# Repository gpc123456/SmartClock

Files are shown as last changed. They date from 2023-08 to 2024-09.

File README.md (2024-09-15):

# SmartClock: A simple but powerful desktop gadget

## Features
- 2.9 "ink screen, excellent viewing Angle and very low power consumption, and can be displayed all the time. 
- Automatic network time synchronization ensures that the time is always accurate. 
- Supports monitoring of environmental information, including temperature, humidity, and air pressure. 
- Switch to Pomodoro Timer at any time to make work and study more efficient. 
- Get weather conditions through the network, showing tomorrow's weather and precipitation probability
- Can be powered by a built-in battery for 7 days, using the universal USB-C charging port 
- Compact and portable, you can take it anywhere. 

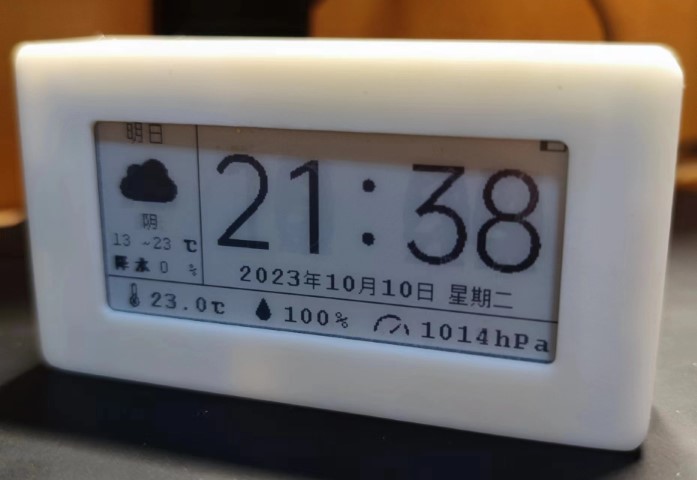
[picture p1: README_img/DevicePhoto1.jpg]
DevicePhoto1


## Version 2.0 Updates:
- Upgrade the device enclosure by no longer using clips but instead using screws to secure the lid and the PCB, making assembly and disassembly easier. 
- Modified the battery level measurement circuit to reduce power consumption during battery level measurements. 
- The PCB uses a four-layer board design for better electrical performance. Additionally, the placement of the temperature and humidity sensor has been optimized to minimize the impact of heat generated during charging on the sensor. 
- Adding a timezone setting feature. 
- The built-in ArduinoJson library simplifies the environmental configuration steps.

## Making Guidelines 
There are the following folders in this project: 
- Hardware
- Model
- bin
- GUI_Picture
- src 

The following will show you how to make a SmartClock by explaining what the files in these folders do.

### Hardware 
In the Hardware folder, you can see the following two types of files: 
- **Compressed package ending with PCB:** These are the production files of the circuit board. You need to provide these two files to the corresponding circuit board manufacturer to make the circuit board used in this project. 
- **PDF file ending with Schematic:** This is the schematic diagram of the circuit board to help you understand the composition of the circuit. 

**Please note**: 
When you complete the circuit board, you also need to weld the corresponding components according to the schematic diagram before it can work normally. The following are some key device selection references: 
- MCU: ESP-12F (ESP8266) 
- E-Paper: E029A01
- Battery: 1000-2000 mAH (Size: [L:52mm, W:34mm, H:<10mm])

### Model
This is the 3D design file of the SmartClock shell, if you need a shell for it, please use a 3D printer to print two files, they are the main body shell and the upper cover. 

**Please note**: 
To secure the top cover, you need to insert knurled nuts into the screw holes on the main body. The size of the knurled nuts and the corresponding parameters of the screws are as follows: 
- knurled nuts: M2*3.5(Outside diameter)*3(Height)
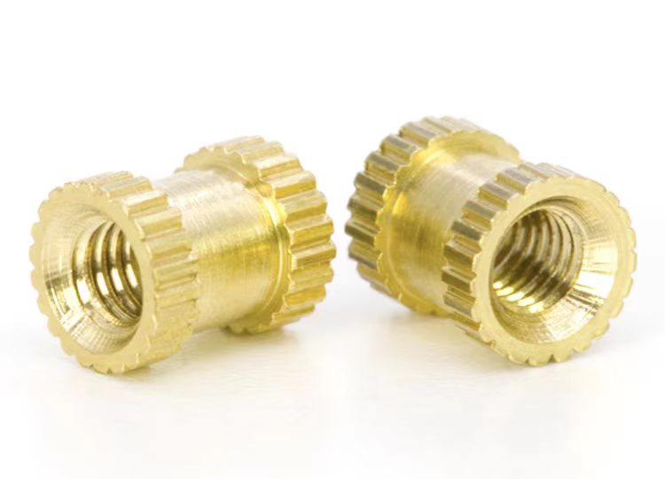
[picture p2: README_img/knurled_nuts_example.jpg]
knurled nuts example
 

- screws: M2*3(Height)
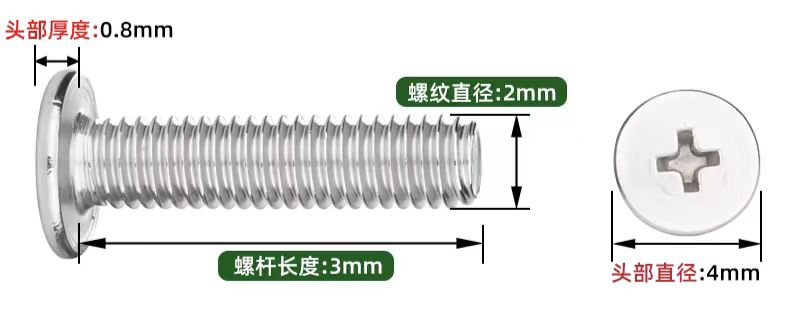
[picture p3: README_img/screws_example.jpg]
screws example


### bin
This is the compiled firmware, and when you finish the circuit, you can use the serial port on the board to write the firmware to it. (PS. The main control chip uses ESP8266, you can find the corresponding finish firmware tutorial on the Internet yourself). 

**However, it is recommended that you build your own firmware instead of using the compiled firmware provided.** Because the weather service API used in the firmware has a free limit, it is not guaranteed to be available at any time. The following will tell you how to compile your own firmware: 
- Register your own account in the https://www.seniverse.com/, and find your API KEY in the console. 
- Open the `Weather` file in the root directory of this project, The ninth line `String httpRequest = "http://api.seniverse.com/v3/weather/daily.json?key=[YOURKEY]&location=ip&language=en`. Change the **YOURKEY** to your API KEY. 
- Download the Arduino on your computer and enter the following in the Additional boards manager URLs in the preferences: `https://arduino.esp8266.com/stable/package_esp8266com_index.json`
- Then follow the image below to locate the Boards Manager：
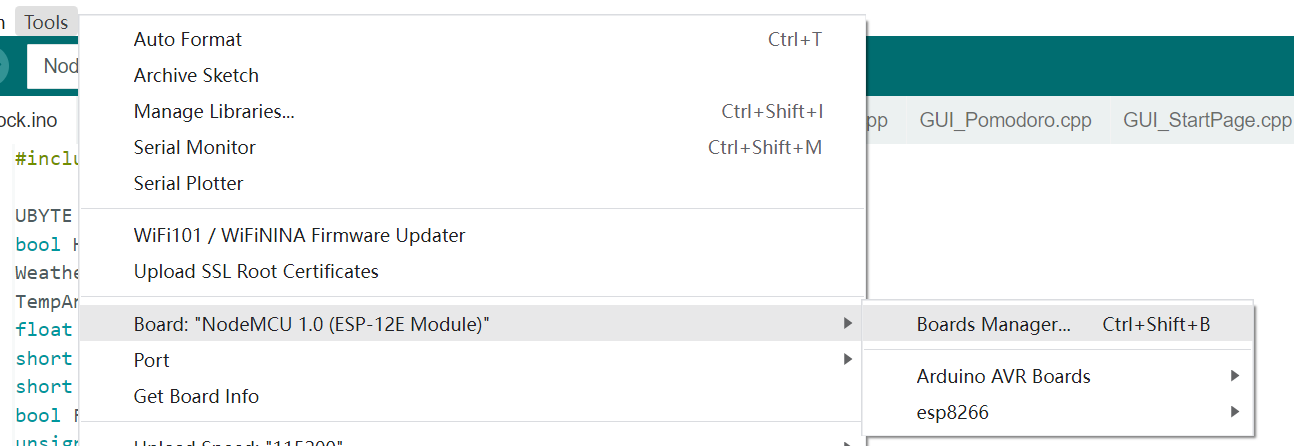
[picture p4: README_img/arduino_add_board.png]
arduino_add_board
    
- Search for esp8266 and install the appropriate toolkit
- Open the `SmartClock.ino` file in the root directory of the project using Arduino
- Connect the board to your computer using a serial port, compile it using Arduino and upload the firmware to the board you made

### GUI_Picture
The source file that draws the image displayed on the screen, you do not need to change it. 

### src 
The underlying drivers, such as screen display, sensor, Wifi management, RTC time management, etc., you do not need to modify them. 

## Use Guidelines
- If there are no problems with your hardware and firmware, follow the on-screen instructions to connect the device to your WIFI after you turn it on
    - Tip: 
    If you see the following information, you may have a problem with your hardware, do a hardware check: 

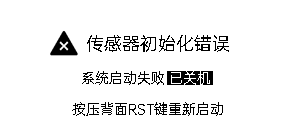
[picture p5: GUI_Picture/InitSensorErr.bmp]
InitSensorErr
    
- If all goes well, you'll end up in the main screen as shown at the beginning of the README. In this interface, turn the device **upside down** to enter Pomodoro Timer mode. 

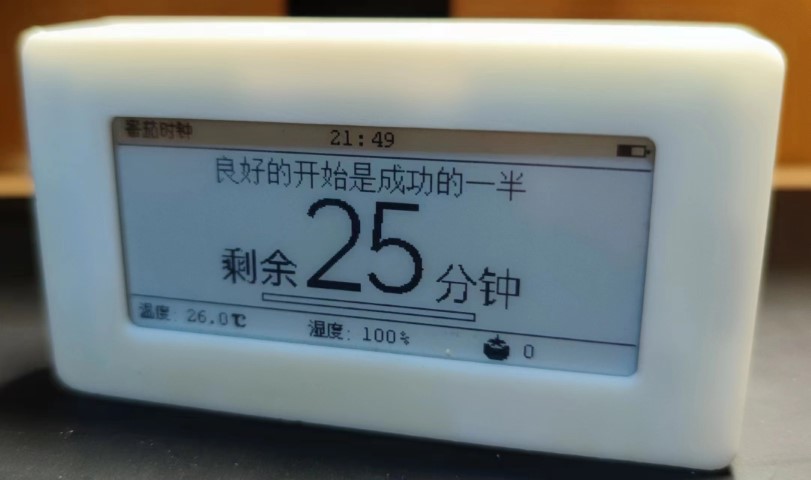
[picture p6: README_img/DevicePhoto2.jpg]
DevicePhoto2
     

- You can exit the mode and return to the main screen by flipping the device back to its original position.

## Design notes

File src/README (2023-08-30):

请注意：若需要对本文件夹中的文件进行的重要修改,先在源文件对应的测试文件夹中修改,待测试稳定后再
复制到本文件夹中.

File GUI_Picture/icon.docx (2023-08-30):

摇一摇：

强错误：

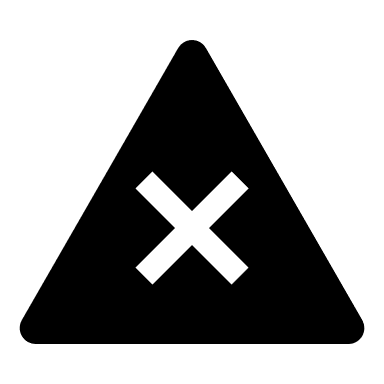
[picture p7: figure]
刺激物

弱错误：

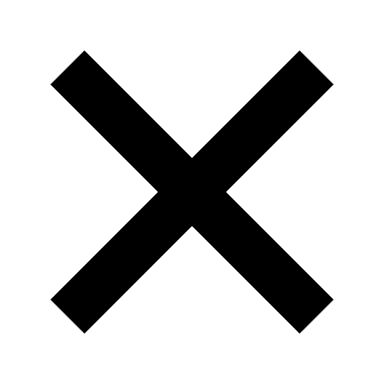
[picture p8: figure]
关闭

正确：

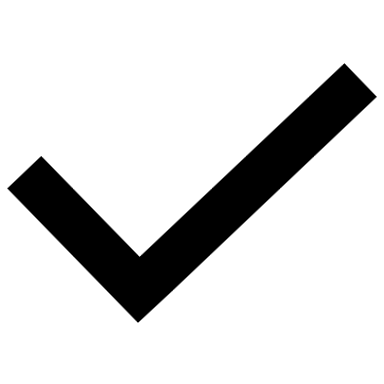
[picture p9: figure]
复选标记

湿度温度：

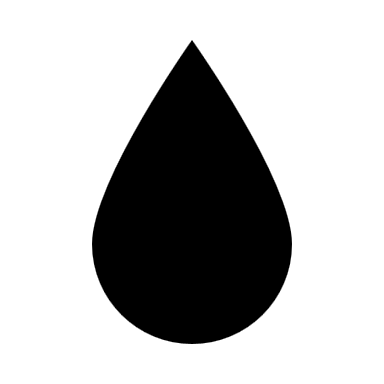
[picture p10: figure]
水
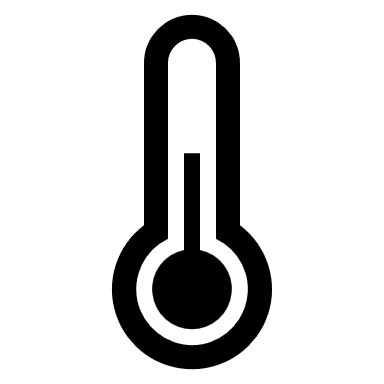
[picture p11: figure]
温度计

气压：

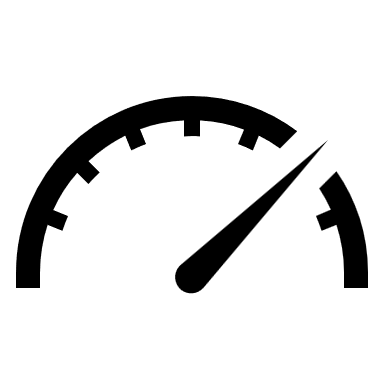
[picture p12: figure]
仪表

操作提问：

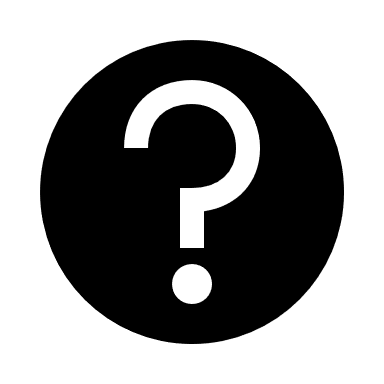
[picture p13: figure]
帮助

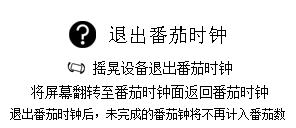
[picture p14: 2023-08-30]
GUI_Picture/Pomodoro_ExitConfirm.bmp

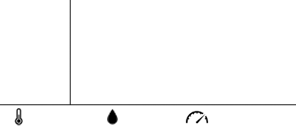
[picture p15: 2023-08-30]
GUI_Picture/HomePageBasic.bmp

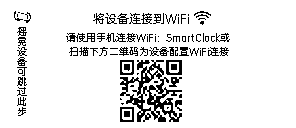
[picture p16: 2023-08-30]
GUI_Picture/ConfigWiFi.bmp

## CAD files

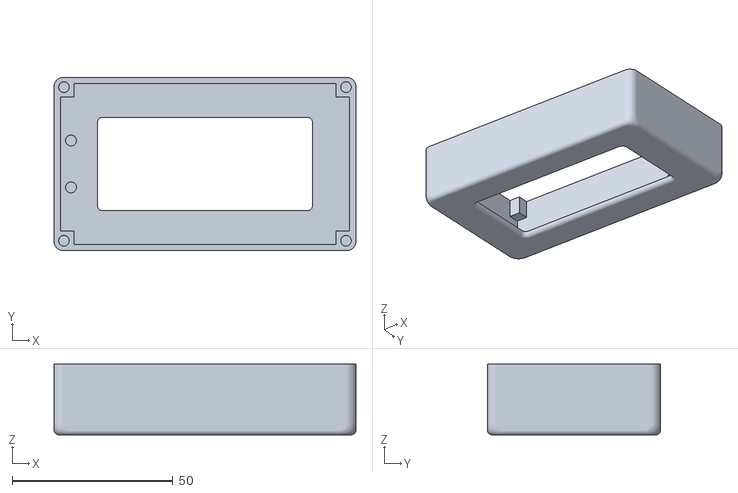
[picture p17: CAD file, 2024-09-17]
Model/Main_body.stl
94.0 x 54.0 x 22.0

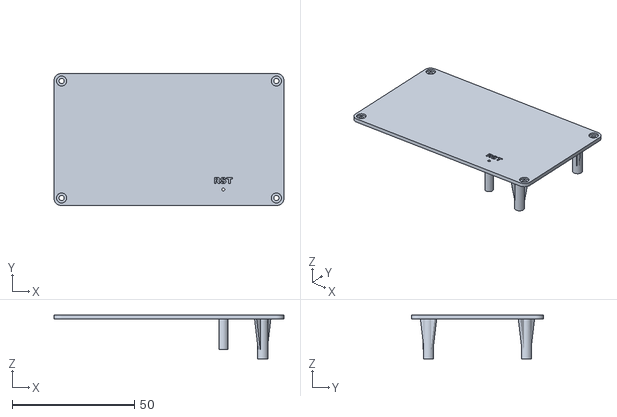
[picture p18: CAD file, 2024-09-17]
Model/Upper_cover.stl
94.0 x 54.0 x 17.8

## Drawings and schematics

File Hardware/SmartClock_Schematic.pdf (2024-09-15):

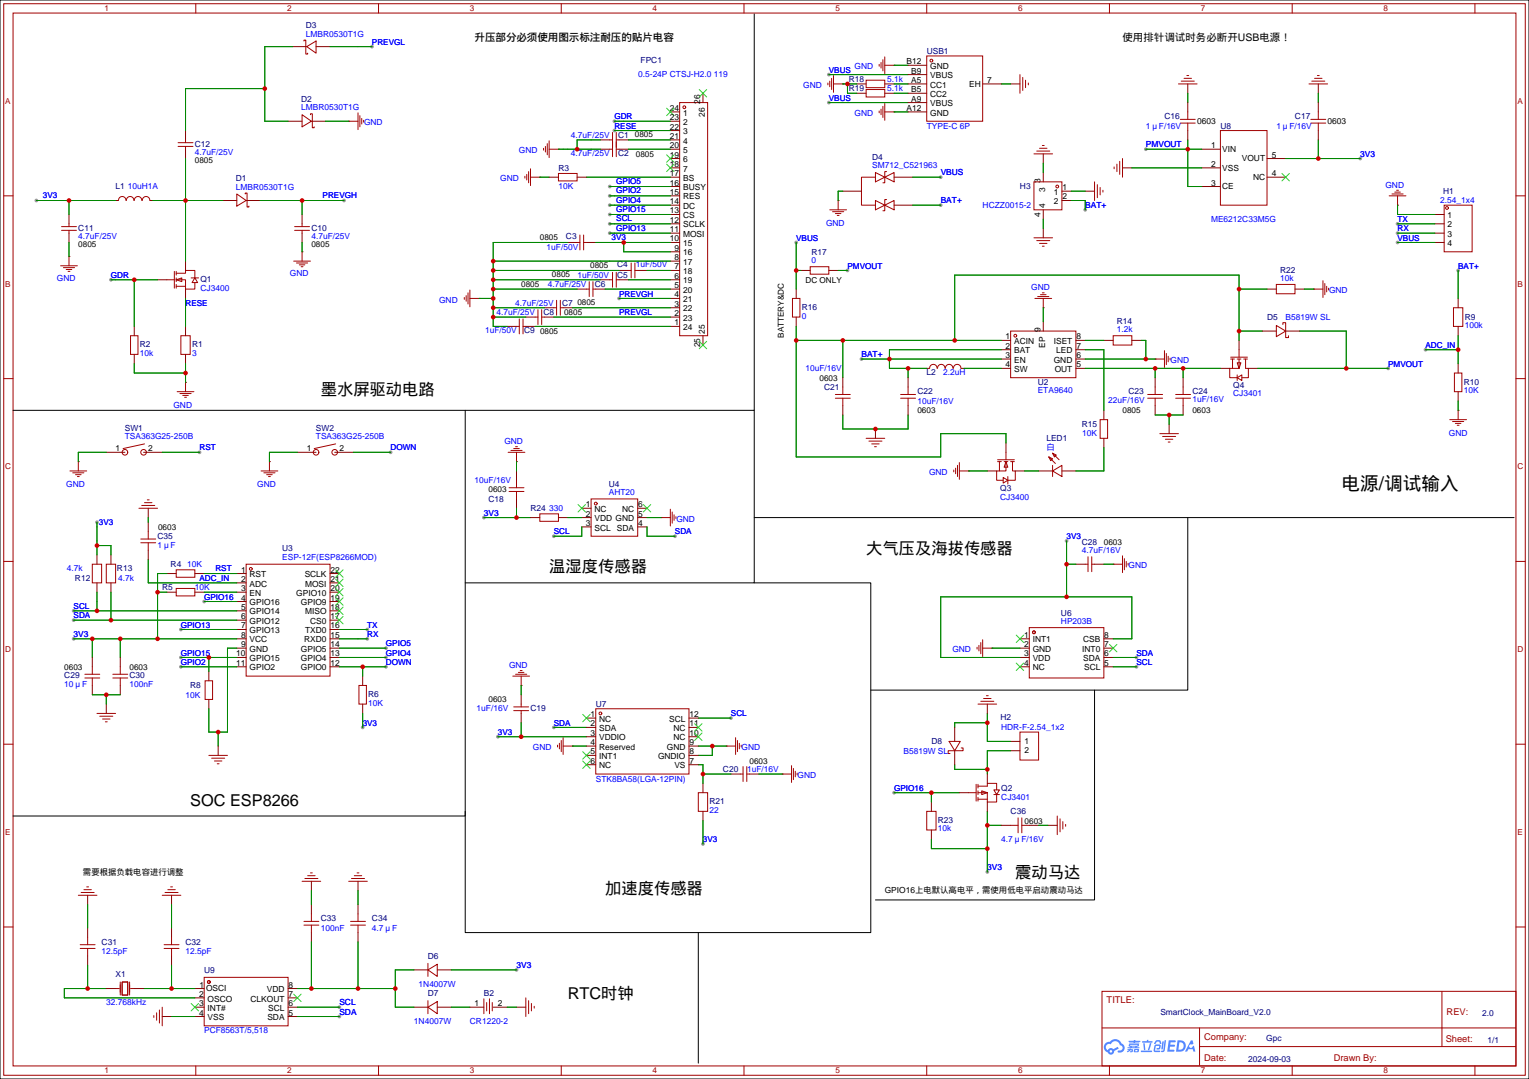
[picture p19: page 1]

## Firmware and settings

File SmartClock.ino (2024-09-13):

#include "SmartClock.h"

UBYTE *Canvas;
bool HomePageFirstDisplayTag;
WeatherData weatherdata;
TempAndRhData tempandrh;
float Nowtemperature;
short Nowhumidity;
short Nowairpressure;
bool FullRefreshTag;
unsigned int RefreshDatatimer;
short NowScreen;

void setup()
{
    weatherdata.DataAvailableTag = WDATA_UNAVAILABLE;
    Serial.begin(115200);
    StartPage();
    if (ConnectWiFi() == FstConnectWiFiDone)
    {
        UpdateTime();
        UpdateWeather(&weatherdata);
    }
    UWORD Imagesize = ((EPD_2IN9_WIDTH % 8 == 0) ? (EPD_2IN9_WIDTH / 8) : (EPD_2IN9_WIDTH / 8 + 1)) * EPD_2IN9_HEIGHT;
    if ((Canvas = (UBYTE *)malloc(Imagesize)) == NULL)
    {
        while (true)
        {
        }
    }
    tempandrh = ReadTempAndRh();
    Nowtemperature = SimplifyTemperatureToOneDecimal(tempandrh.Temperature);
    Nowhumidity = round(tempandrh.Humidity);
    Nowairpressure = round(ReadAirPressure());
    RefreshDatatimer = 1;
    FullRefreshTag = NEED_FULLREFRESH;
    HomePageFirstDisplayTag == 0;
    NowScreen = HOMEPAGE;
}

TimeAndDate NowTime;
short OldHour;
short OldMinute;

void loop()
{
    wifi_station_disconnect();
    wifi_set_opmode(NULL_MODE);
    wifi_fpm_set_sleep_type(LIGHT_SLEEP_T);
    wifi_fpm_open();
    wifi_fpm_do_sleep(500000); // Sleep range = 10000 ~ 268,435,454 uS (0xFFFFFFE, 2^28-1)
    delay(500 + 1);            // delay needs to be 1 mS longer than sleep or it only goes into Modem Sleep

    RefreshDatatimer++;
    Wire.begin(12, 14);

    if (NowScreen == HOMEPAGE)
    {
        NowTime = ReadTimeAndDate();
        if (HomePageFirstDisplayTag == 0)
        {
            WiFi.forceSleepBegin(0xFFFFFFF);
            delay(10);
            HomePage_FullRefresh(Canvas, NowTime, weatherdata, Nowtemperature, Nowhumidity, Nowairpressure, ReadBatteryLevel());
            OldHour = NowTime.hour;
            OldMinute = NowTime.minute;
            HomePageFirstDisplayTag = 1;
        }

        if ((NowTime.hour == 12 && NowTime.minute == 0 && FullRefreshTag == NEED_FULLREFRESH) || (NowTime.hour == 0 && NowTime.minute == 0 && FullRefreshTag == NEED_FULLREFRESH))
        {
            WiFi.forceSleepBegin(0xFFFFFFF);
            delay(10);
            HomePage_FullRefresh(Canvas, NowTime, weatherdata, Nowtemperature, Nowhumidity, Nowairpressure, ReadBatteryLevel());
            OldHour = NowTime.hour;
            OldMinute = NowTime.minute;
            FullRefreshTag = NONEED_FULLREFRESH;
        }
        if (NowTime.minute != OldMinute)
        {
            WiFi.forceSleepBegin(0xFFFFFFF);
            delay(10);
            HomePage_PartRefreshTime_Temperature_Humidity_Airpressure_Battery(Canvas, NowTime, Nowtemperature, Nowhumidity, Nowairpressure, ReadBatteryLevel());
            OldMinute = NowTime.minute;
        }
        if (NowTime.hour != OldHour)
        {
            WiFi.forceSleepBegin(0xFFFFFFF);
            delay(10);
            HomePage_PartRefreshWeather(Canvas, weatherdata, NowTime);
            OldHour = NowTime.hour;
            FullRefreshTag = NEED_FULLREFRESH; // 全刷1小时后再重置全刷标志位，防止重复刷新
        }

        if (RefreshDatatimer % 3 == 0)
        {
            // WiFi.forceSleepBegin(0xFFFFFFF);
            // delay(10);
            if (Direction() == FRONT_DOWN)
            {
                NowScreen = POMODORO;
                PomodoroFirstStartFlag = POMODORO_FIRST_START;
            }
        }
    }
    else if (NowScreen == POMODORO)
    {
        App_Pomodoro(Canvas, ReadBatteryLevel(), Nowtemperature, Nowhumidity);
    }

    if (RefreshDatatimer % 50 == 0)
    {
        WiFi.forceSleepBegin(0xFFFFFFF);
        delay(10);
        tempandrh = ReadTempAndRh();
        Nowtemperature = SimplifyTemperatureToOneDecimal(tempandrh.Temperature);
        Nowhumidity = round(tempandrh.Humidity);
        Nowairpressure = round(ReadAirPressure());
    }

    if (RefreshDatatimer % 7200 == 0)
    {
        WiFi.forceSleepWake();
        wifi_fpm_close();              //	disable	force	sleep	function
        wifi_set_opmode(STATION_MODE); //	set	station	mode
        wifi_station_connect();        //	connect	to	AP
        delay(5000);
        Serial.println(UpdateTime());
        if (UpdateWeather(&weatherdata) == UPDATE_WEATHER_SUCCESS)
        {
            Serial.println("Weather Update!");
            RefreshDatatimer == 1;
        }
    }
    if (RefreshDatatimer == 4294967293)
    {
        RefreshDatatimer = 1; // 防止数据溢出
    }
}

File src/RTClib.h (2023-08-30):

/**************************************************************************/
/*!
  @file     RTClib.h

  Original library by JeeLabs http://news.jeelabs.org/code/, released to the
  public domain

  License: MIT (see LICENSE)

  This is a fork of JeeLab's fantastic real time clock library for Arduino.

  For details on using this library with an RTC module like the DS1307, PCF8523,
  or DS3231, see the guide at:
  https://learn.adafruit.com/ds1307-real-time-clock-breakout-board-kit/overview

  Adafruit invests time and resources providing this open source code,
  please support Adafruit and open-source hardware by purchasing
  products from Adafruit!
*/
/**************************************************************************/

#ifndef _RTCLIB_H_
#define _RTCLIB_H_

#include "Adafruit_I2CDevice.h"
#include <Arduino.h>

class TimeSpan;

/** Constants */
#define SECONDS_PER_DAY 86400L ///< 60 * 60 * 24
#define SECONDS_FROM_1970_TO_2000                                              \
  946684800 ///< Unixtime for 2000-01-01 00:00:00, useful for initialization

/** DS1307 SQW pin mode settings */
enum Ds1307SqwPinMode {
  DS1307_OFF = 0x00,            // Low
  DS1307_ON = 0x80,             // High
  DS1307_SquareWave1HZ = 0x10,  // 1Hz square wave
  DS1307_SquareWave4kHz = 0x11, // 4kHz square wave
  DS1307_SquareWave8kHz = 0x12, // 8kHz square wave
  DS1307_SquareWave32kHz = 0x13 // 32kHz square wave
};

/** DS3231 SQW pin mode settings */
enum Ds3231SqwPinMode {
  DS3231_OFF = 0x1C,            /**< Off */
  DS3231_SquareWave1Hz = 0x00,  /**<  1Hz square wave */
  DS3231_SquareWave1kHz = 0x08, /**<  1kHz square wave */
  DS3231_SquareWave4kHz = 0x10, /**<  4kHz square wave */
  DS3231_SquareWave8kHz = 0x18  /**<  8kHz square wave */
};

/** DS3231 Alarm modes for alarm 1 */
enum Ds3231Alarm1Mode {
  DS3231_A1_PerSecond = 0x0F, /**< Alarm once per second */
  DS3231_A1_Second = 0x0E,    /**< Alarm when seconds match */
  DS3231_A1_Minute = 0x0C,    /**< Alarm when minutes and seconds match */
  DS3231_A1_Hour = 0x08,      /**< Alarm when hours, minutes
                                   and seconds match */
  DS3231_A1_Date = 0x00,      /**< Alarm when date (day of month), hours,
                                   minutes and seconds match */
  DS3231_A1_Day = 0x10        /**< Alarm when day (day of week), hours,
                                   minutes and seconds match */
};
/** DS3231 Alarm modes for alarm 2 */
enum Ds3231Alarm2Mode {
  DS3231_A2_PerMinute = 0x7, /**< Alarm once per minute
                                  (whenever seconds are 0) */
  DS3231_A2_Minute = 0x6,    /**< Alarm when minutes match */
  DS3231_A2_Hour = 0x4,      /**< Alarm when hours and minutes match */
  DS3231_A2_Date = 0x0,      /**< Alarm when date (day of month), hours
                                  and minutes match */
  DS3231_A2_Day = 0x8        /**< Alarm when day (day of week), hours
                                  and minutes match */
};
/** PCF8523 INT/SQW pin mode settings */
enum Pcf8523SqwPinMode {
  PCF8523_OFF = 7,             /**< Off */
  PCF8523_SquareWave1HZ = 6,   /**< 1Hz square wave */
  PCF8523_SquareWave32HZ = 5,  /**< 32Hz square wave */
  PCF8523_SquareWave1kHz = 4,  /**< 1kHz square wave */
  PCF8523_SquareWave4kHz = 3,  /**< 4kHz square wave */
  PCF8523_SquareWave8kHz = 2,  /**< 8kHz square wave */
  PCF8523_SquareWave16kHz = 1, /**< 16kHz square wave */
  PCF8523_SquareWave32kHz = 0  /**< 32kHz square wave */
};

/** PCF8523 Timer Source Clock Frequencies for Timers A and B */
enum PCF8523TimerClockFreq {
  PCF8523_Frequency4kHz = 0,   /**< 1/4096th second = 244 microseconds,
                                    max 62.256 milliseconds */
  PCF8523_Frequency64Hz = 1,   /**< 1/64th second = 15.625 milliseconds,
                                    max 3.984375 seconds */
  PCF8523_FrequencySecond = 2, /**< 1 second, max 255 seconds = 4.25 minutes */
  PCF8523_FrequencyMinute = 3, /**< 1 minute, max 255 minutes = 4.25 hours */
  PCF8523_FrequencyHour = 4,   /**< 1 hour, max 255 hours = 10.625 days */
};

/** PCF8523 Timer Interrupt Low Pulse Width options for Timer B only */
enum PCF8523TimerIntPulse {
  PCF8523_LowPulse3x64Hz = 0,  /**<  46.875 ms   3/64ths second */
  PCF8523_LowPulse4x64Hz = 1,  /**<  62.500 ms   4/64ths second */
  PCF8523_LowPulse5x64Hz = 2,  /**<  78.125 ms   5/64ths second */
  PCF8523_LowPulse6x64Hz = 3,  /**<  93.750 ms   6/64ths second */
  PCF8523_LowPulse8x64Hz = 4,  /**< 125.000 ms   8/64ths second */
  PCF8523_LowPulse10x64Hz = 5, /**< 156.250 ms  10/64ths second */
  PCF8523_LowPulse12x64Hz = 6, /**< 187.500 ms  12/64ths second */
  PCF8523_LowPulse14x64Hz = 7  /**< 218.750 ms  14/64ths second */
};

/** PCF8523 Offset modes for making temperature/aging/accuracy adjustments */
enum Pcf8523OffsetMode {
  PCF8523_TwoHours = 0x00, /**< Offset made every two hours */
  PCF8523_OneMinute = 0x80 /**< Offset made every minute */
};

/** PCF8563 CLKOUT pin mode settings */
enum Pcf8563SqwPinMode {
  PCF8563_SquareWaveOFF = 0x00,  /**< Off */
  PCF8563_SquareWave1Hz = 0x83,  /**< 1Hz square wave */
  PCF8563_SquareWave32Hz = 0x82, /**< 32Hz square wave */
  PCF8563_SquareWave1kHz = 0x81, /**< 1kHz square wave */
  PCF8563_SquareWave32kHz = 0x80 /**< 32kHz square wave */
};
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

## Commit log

2023-10-10 Update README; 修改Weather模块文件，删除其中的APIKEY；新增原理图；新增README图片
2024-09-13 add gitignore; 新增时区设置功能；内置ArduinoJson相关依赖；修改NTP请求服务器
2024-09-13 修复多次时间偏移，导致最终偏移结果错误的BUG
2024-09-15 由于硬件设计改动，更新电池电量计算方法
2024-09-15 Update BIN, PCB, Schematic, Shell Model
    [MainBoard_2022-10-03_B.stl, MainBoard_2022-10-03_T.stl, Main_body.stl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]
2024-09-15 UPDATE Upper_cover model
    [Upper_cover.stl]
2024-09-15 Update shell model
    [Main_body.stl, Upper_cover.stl]
2024-09-17 update model
    [Main_body.stl, Upper_cover.stl]
